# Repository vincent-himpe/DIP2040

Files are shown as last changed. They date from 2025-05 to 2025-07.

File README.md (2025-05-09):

# DIP2040
## An RP2040 in DIP40 PACKAGE with bare minimum on-board circuitry

### Features
- on-board Flash
- on-board 3V reference (LM4040-3.0). Can be disabled by opening a solder bridge.
- ESD protected, sturdy, through-hole, USB-C connector
- Reset and BOObuttones. Boot button also available under the USB-C connector so you can poke it with a paperclip
- Heartbeat LED. can be disabled using a solder bridge
- USB powered 3V3 regulator. Can be strapped to the 3V3 bus using a solder bridge.
- External 3V3 input for self-powered operation
- All GPIO brought out on the pins.  (except the QSPI for the flash). Nothing is hidden.
- Fits standard 40 pin DIP socket
- USB connector extends past the board so you can mount it close to an enclosure wall and have the USB connector stick out.
- 4-layer PCB with ground plane and impedance control.
- 3D STEP model avaiabale
- Design released under Creative Commons Zero Universal.
- Source files available (Altium V25 format)
- Production data available for DKred ( Digikey's PCB service ) and others ( Standard Gerber-X format )

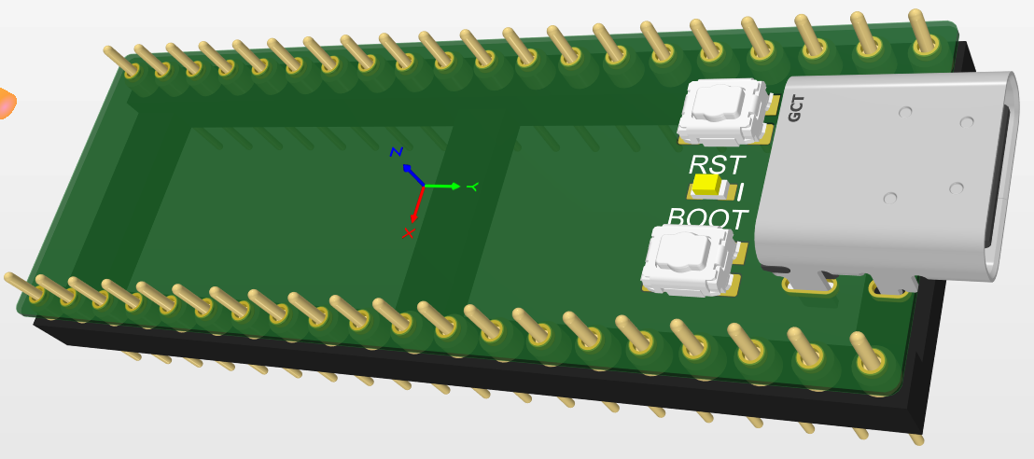
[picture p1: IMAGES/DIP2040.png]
3D view


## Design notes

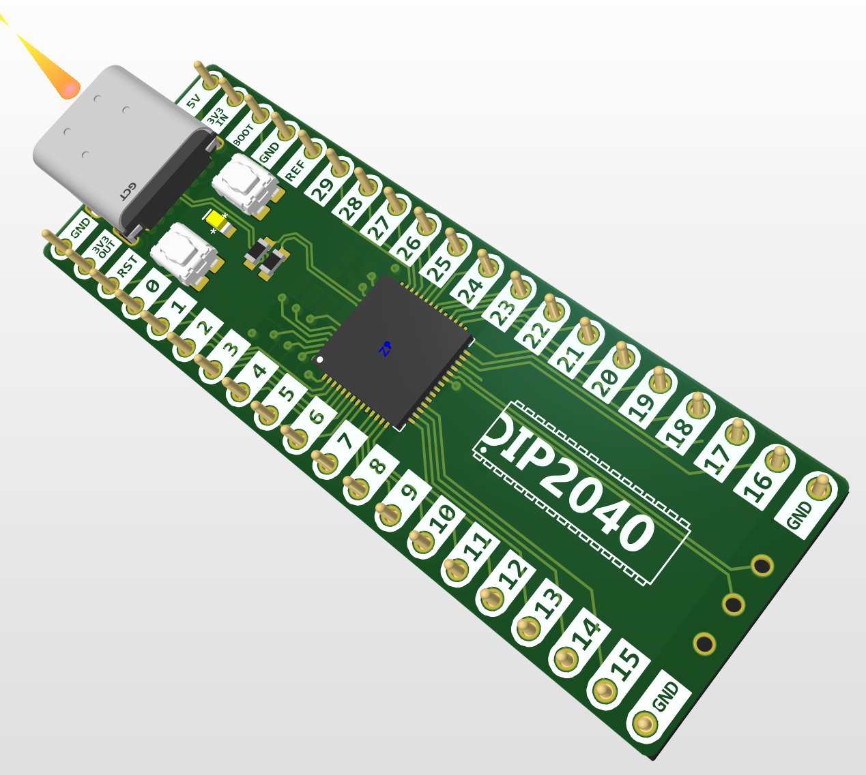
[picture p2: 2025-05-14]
IMAGES/DIP2040B.png

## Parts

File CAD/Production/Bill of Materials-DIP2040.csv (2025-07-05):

Description | Designator | Quantity | LCSC
CAPACITOR,CERAMIC,100nF,16V,X7R,0402 | C1, C7, C10, C11, C13, C14, C15, C16, C17, C20, C22, C23, C26, C27 | 14 | C60474
CAPACITOR,CERAMIC,22uF,16V,X5R,0603 | C2, C3, C4, C5 | 4 | C2762594
CAPACITOR,CERAMIC,4u7,10V,X5R,0402 | C6, C8, C9, C12, C24, C25 | 6 | C1705
CAPACITOR,CERAMIC,15pF,50V,C0G,0402 | C18, C19 | 2 | C3906764
DIODE,TVS,DUAL,UNIDIRECTIONAL,USB | D1 | 1 | C22358704
LED,BLUE,0603 | D2 | 1 | C965807
USB-C, RIGHT ANGLE, [NoValue], RESISTOR,100R,1%,100mW,0603 (1608), IC,PMIC,IDEAL DIODE ORING CONTROLLER | J1, J2, R9, SW1, SW2, SW3, U1, U2 | 8
IND,4.7uH,1.06A,3X3, NRH3012T4R7MN | L1 | 1 | C5159666, C42429096
RESISTOR,5K1,1%,63mW,0402 (1005) | R1, R3 | 2 | C105872
RESISTOR,27R,1%,63mW,0402 (1005) | R4, R5 | 2 | C138021
RESISTOR,10K,1%,63mW,0402 (1005) | R6, R7 | 2 | C60490
RESISTOR,1K,1%,63mW,0402 (1005) | R8, R10 | 2 | C106235
IC,FLASH,QSPI,16Mx8 | U3 | 1 | C97521
IC,PMIC,STEP-DOWN, 2A 3.3V | U4 | 1 | C780769
IC,VOLTAGE REFERENCE,3.0V | U5 | 1 | C460608
IC,RTC,I2C,DS3231M | U6 | 1 | C107410
XTAL,12MHZ,RP2350 | X1 | 1 | C20625731

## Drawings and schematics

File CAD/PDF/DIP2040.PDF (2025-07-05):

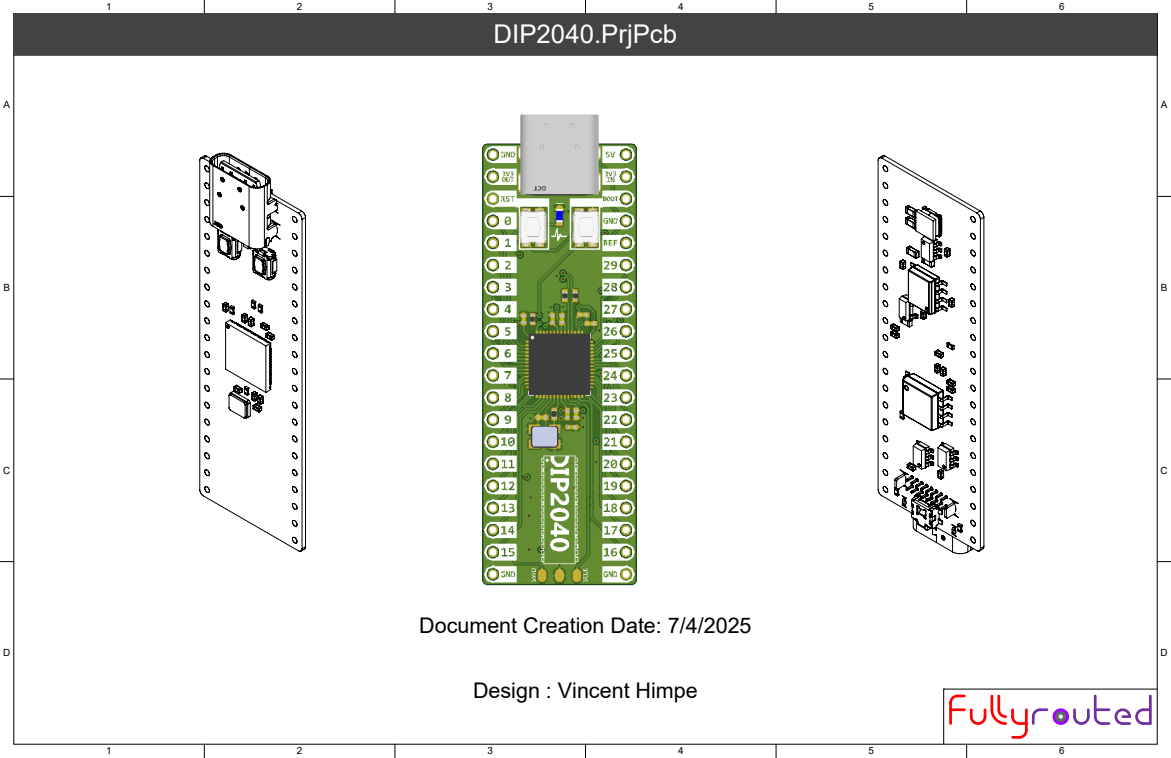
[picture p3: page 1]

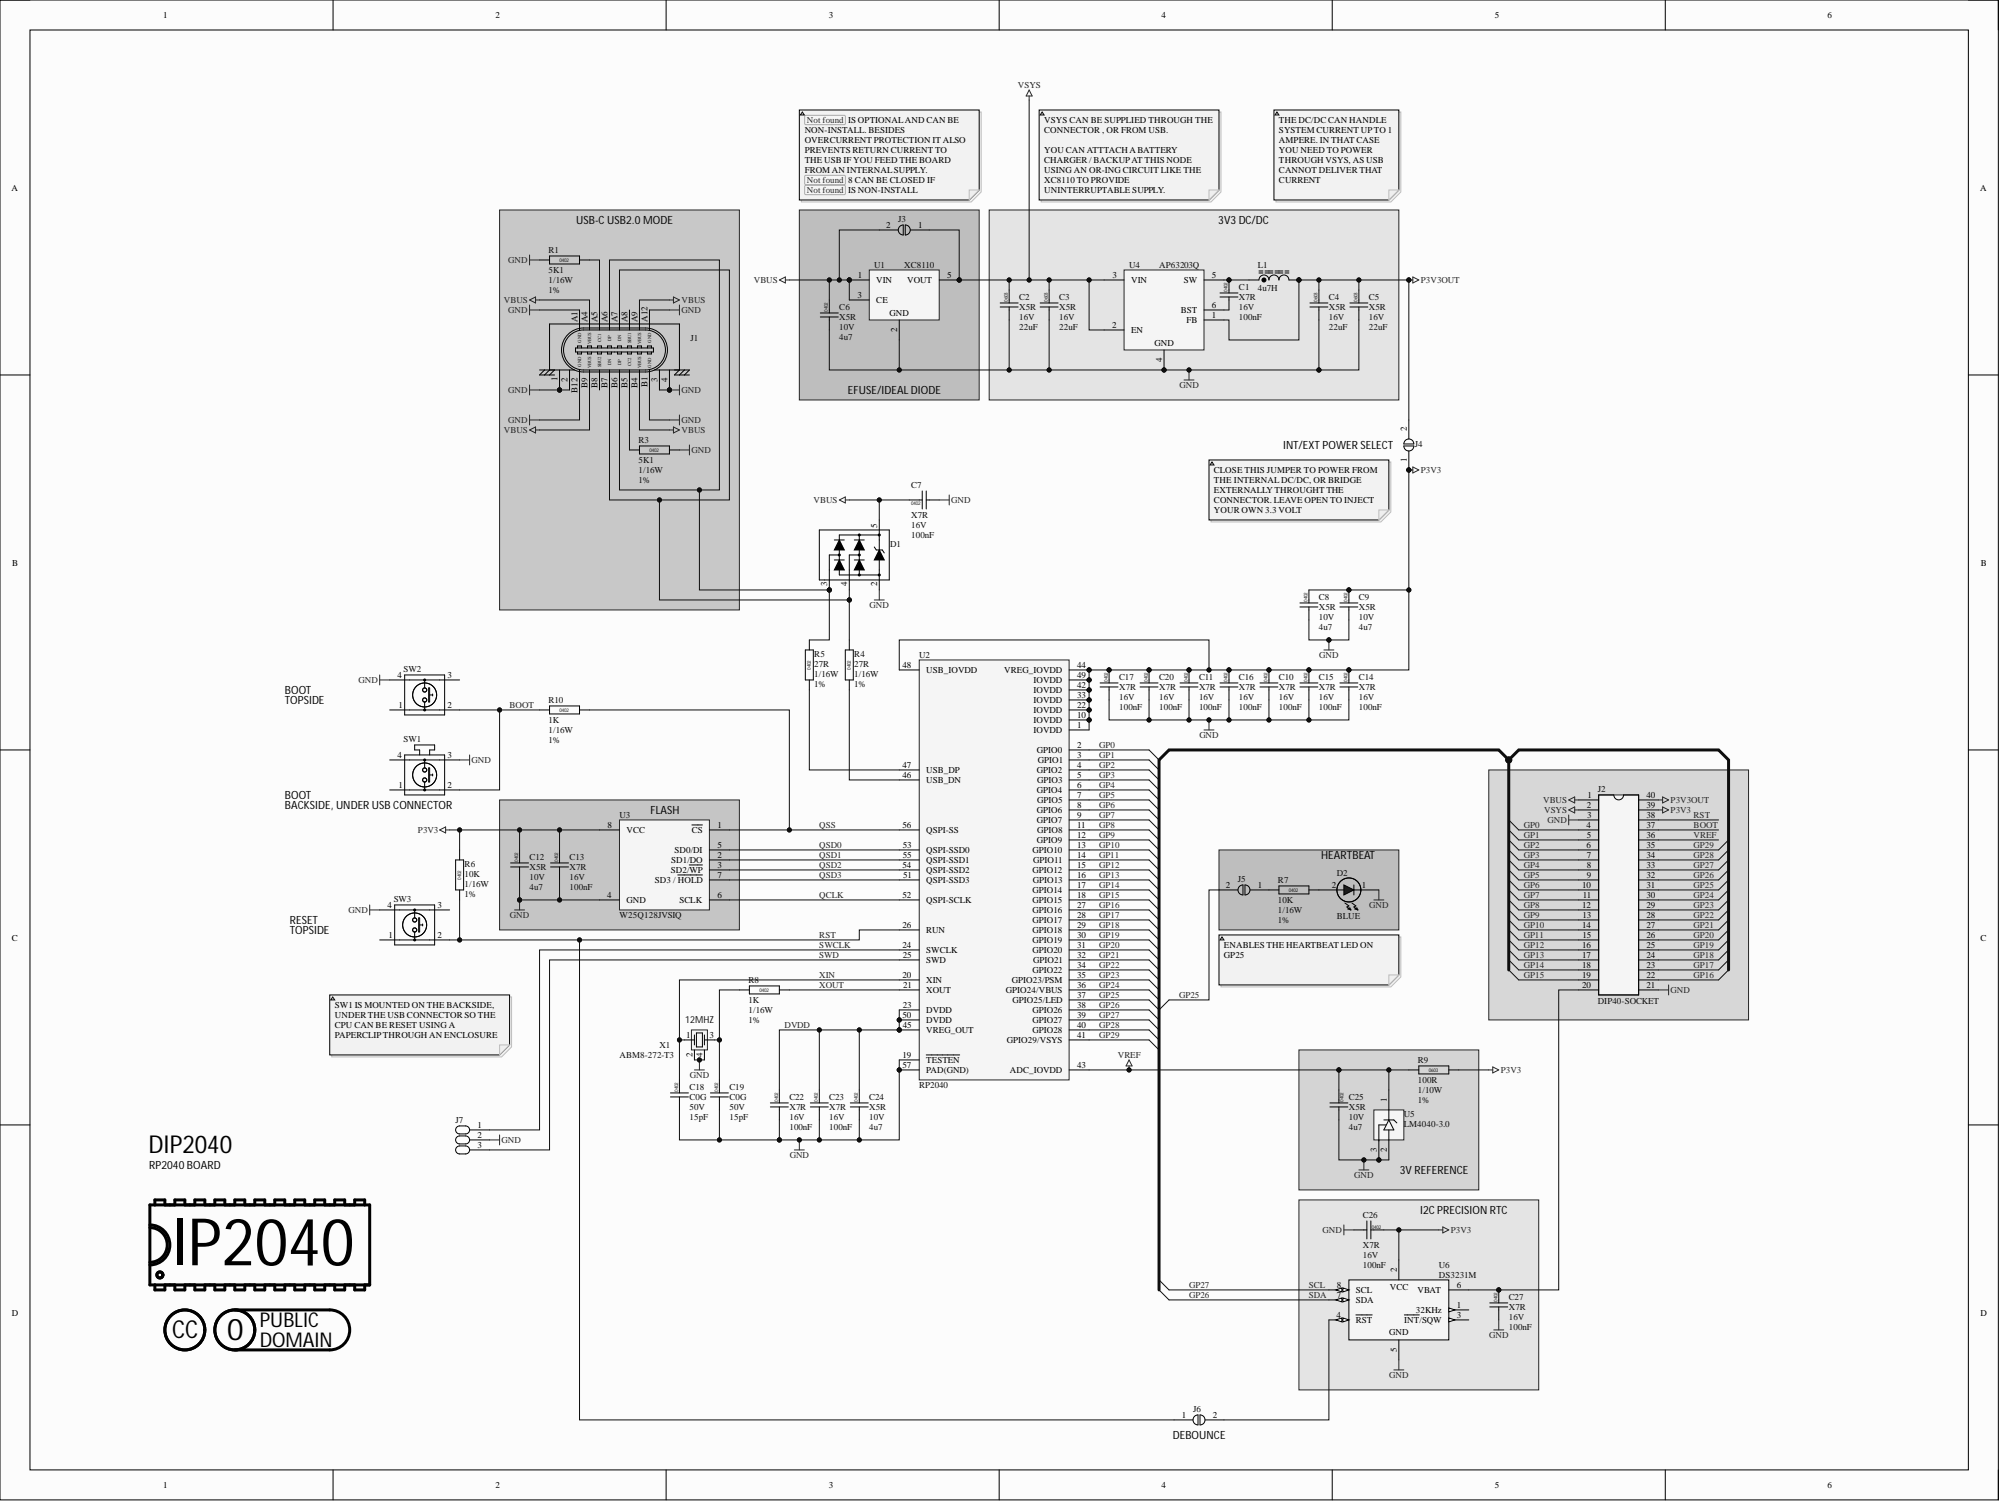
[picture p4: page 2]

Not found IS OPTIONALAND CAN BE
NON-INSTALL. BESIDES
OVERCURRENT PROTECTION IT ALSO
PREVENTS RETURN CURRENT TO
THE USB IF YOU FEED THE BOARD
FROM AN INTERNALSUPPLY.
Not found 8 CAN BE CLOSED IF
Not found IS NON-INSTALL

VSYS CAN BE SUPPLIED THROUGH THE
CONNECTOR , OR FROM USB.

THE DC/DC CAN HANDLE
SYSTEM CURRENT UPTO 1
AMPERE. IN THAT CASE
YOU NEED TO POWER
THROUGH VSYS, AS USB
CANNOT DELIVER THAT
CURRENT

YOU CAN ATTTACH A BATTERY
CHARGER / BACKUP AT THIS NODE
USING AN OR-ING CIRCUIT LIKE THE
XC8110 TO PROVIDE
UNINTERRUPTABLE SUPPLY.

INT/EXT POWER SELECT

CLOSE THIS JUMPER TO POWER FROM
THE INTERNAL DC/DC, OR BRIDGE
EXTERNALLY THROUGHT THE
CONNECTOR. LEAVE OPEN TO INJECT
YOUR OWN 3.3 VOLT

BOOT
BACKSIDE, UNDER USB CONNECTOR

ENABLES THE HEARTBEAT LED ON

SW1 IS MOUNTED ON THE BACKSIDE,
UNDER THE USB CONNECTOR SO THE
CPU CAN BE RESET USING A
PAPERCLIP THROUGH AN ENCLOSURE

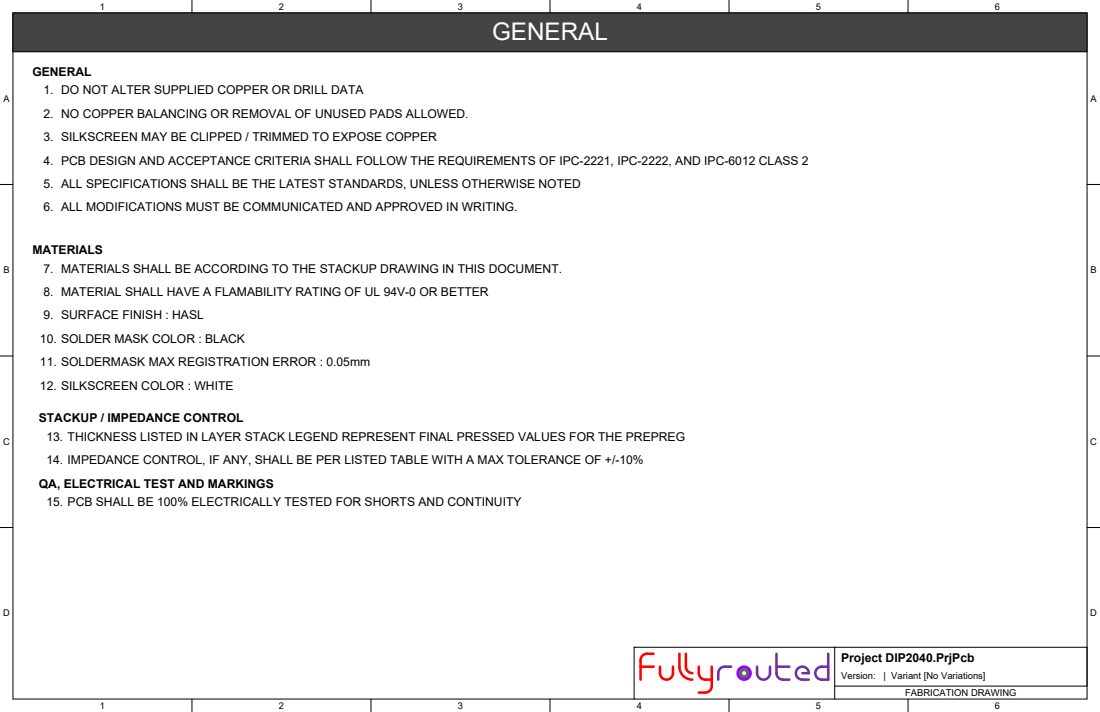
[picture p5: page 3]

GENERAL
1. DO NOT ALTER SUPPLIED COPPER OR DRILL DATA
2. NO COPPER BALANCING OR REMOVAL OF UNUSED PADS ALLOWED.
3. SILKSCREEN MAY BE CLIPPED / TRIMMED TO EXPOSE COPPER
4. PCB DESIGN AND ACCEPTANCE CRITERIA SHALL FOLLOW THE REQUIREMENTS OF IPC-2221, IPC-2222, AND IPC-6012 CLASS 2
5. ALL SPECIFICATIONS SHALL BE THE LATEST STANDARDS, UNLESS OTHERWISE NOTED
6. ALL MODIFICATIONS MUST BE COMMUNICATED AND APPROVED IN WRITING.

MATERIALS
7. MATERIALS SHALL BE ACCORDING TO THE STACKUP DRAWING IN THIS DOCUMENT.
8. MATERIAL SHALL HAVE A FLAMABILITY RATING OF UL 94V-0 OR BETTER
9. SURFACE FINISH : HASL
10. SOLDER MASK COLOR : BLACK
11. SOLDERMASK MAX REGISTRATION ERROR : 0.05mm
12. SILKSCREEN COLOR : WHITE

STACKUP / IMPEDANCE CONTROL
13. THICKNESS LISTED IN LAYER STACK LEGEND REPRESENT FINAL PRESSED VALUES FOR THE PREPREG
14. IMPEDANCE CONTROL, IF ANY, SHALL BE PER LISTED TABLE WITH A MAX TOLERANCE OF +/-10%
QA, ELECTRICAL TEST AND MARKINGS
15. PCB SHALL BE 100% ELECTRICALLY TESTED FOR SHORTS AND CONTINUITY

Project DIP2040.PrjPcb
Version: | Variant [No Variations]

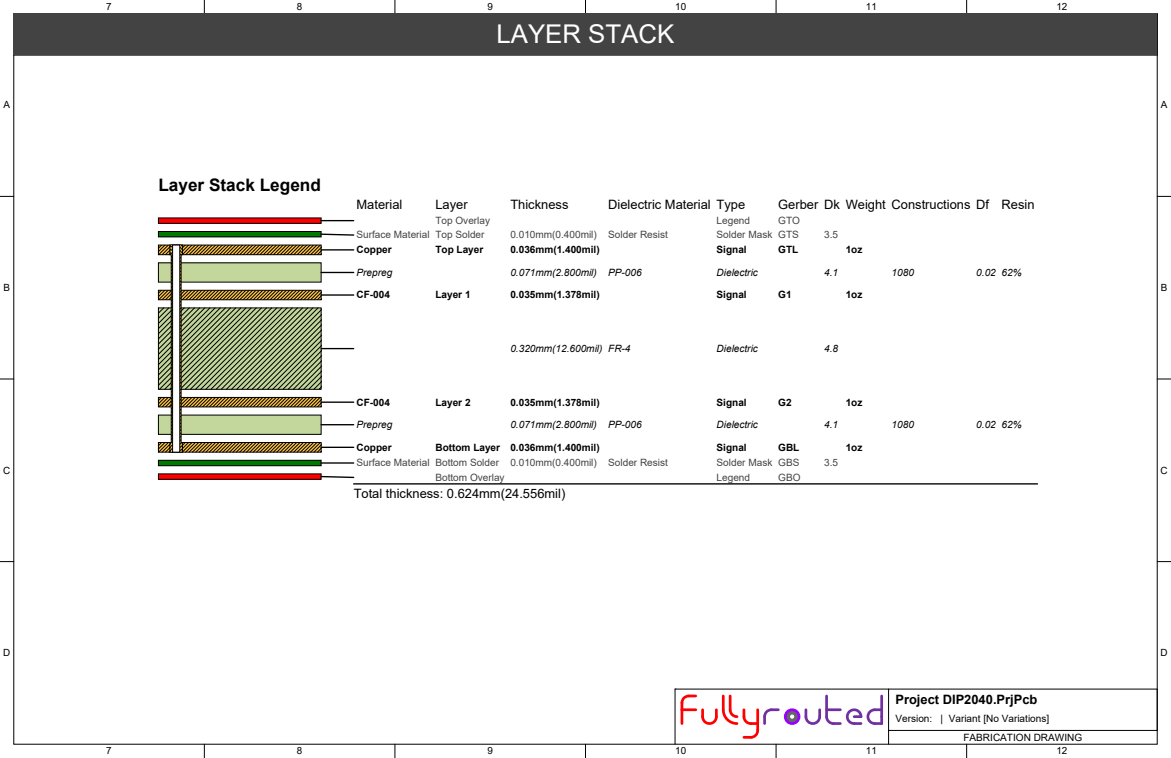
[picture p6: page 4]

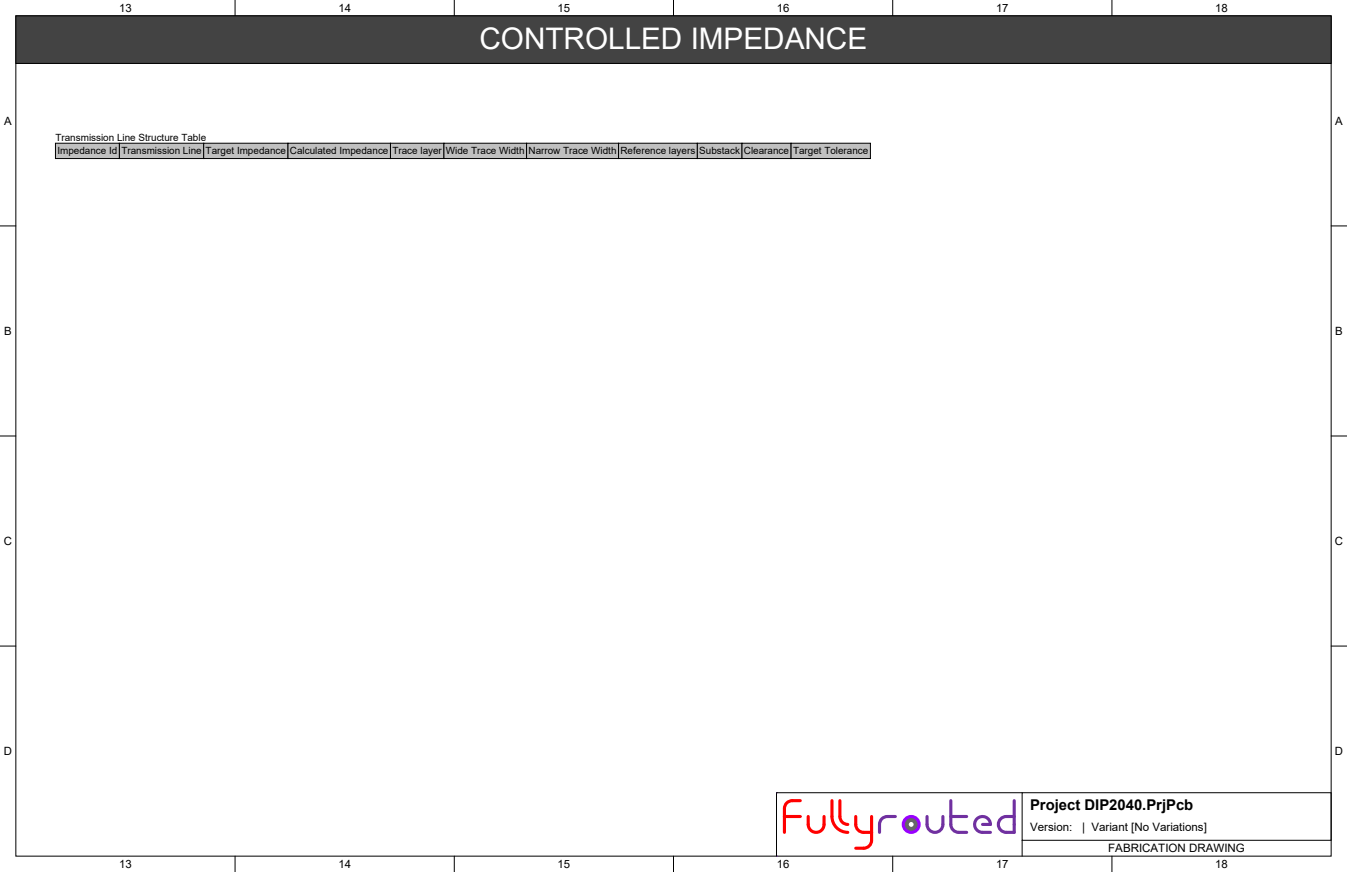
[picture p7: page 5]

Transmission Line Structure Table

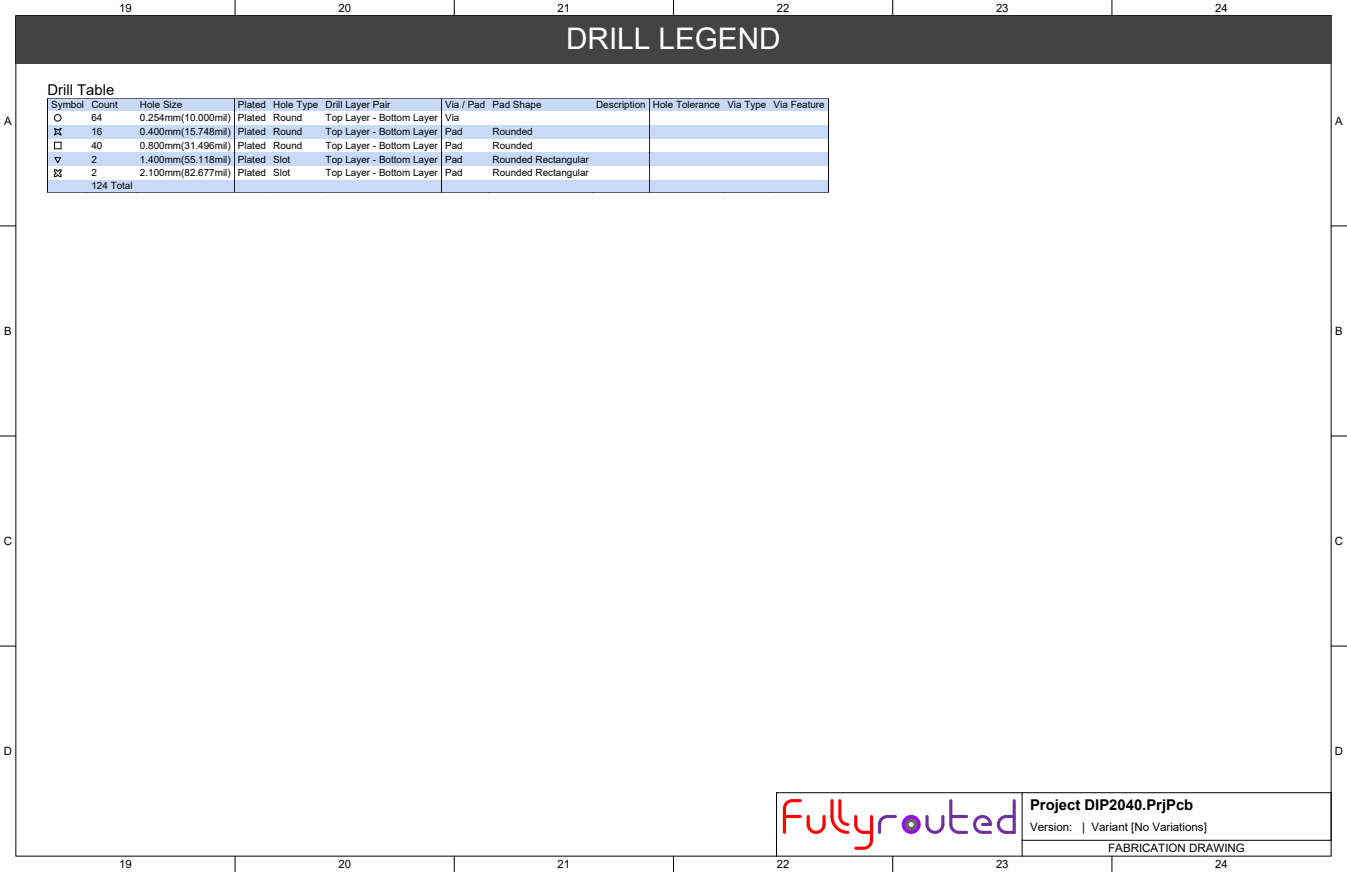
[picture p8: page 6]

Symbol | Count | Hole Size | Plated | Hole Type | Drill Layer Pair | Via / Pad | Pad Shape | Description | Hole Tolerance | Via Type | Via Feature

64 | 0.254mm(10.000mil) | Plated | Round | Top Layer - Bottom Layer | Via
16 | 0.400mm(15.748mil) | Plated | Round | Top Layer - Bottom Layer | Pad | Rounded
40 | 0.800mm(31.496mil) | Plated | Round | Top Layer - Bottom Layer | Pad | Rounded
2 | 1.400mm(55.118mil) | Plated | Slot | Top Layer - Bottom Layer | Pad | Rounded Rectangular
2 | 2.100mm(82.677mil) | Plated | Slot | Top Layer - Bottom Layer | Pad | Rounded Rectangular
124 Total

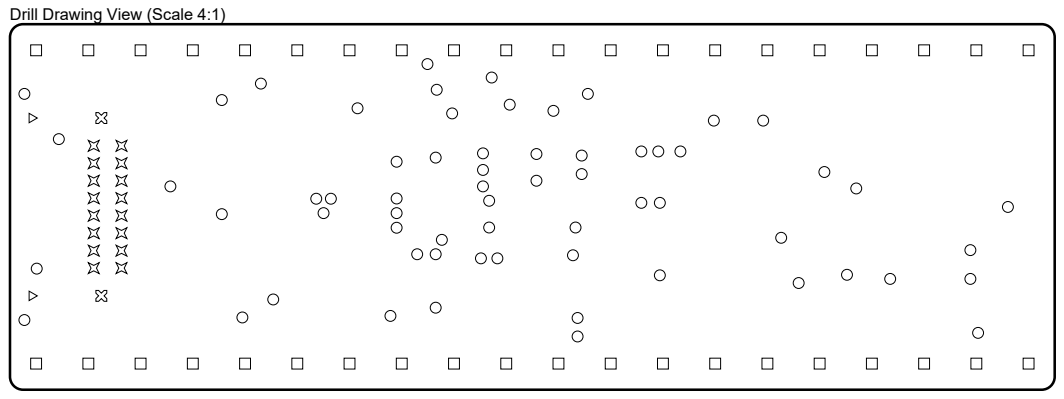
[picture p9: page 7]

Drill Drawing View (Scale 4:1)

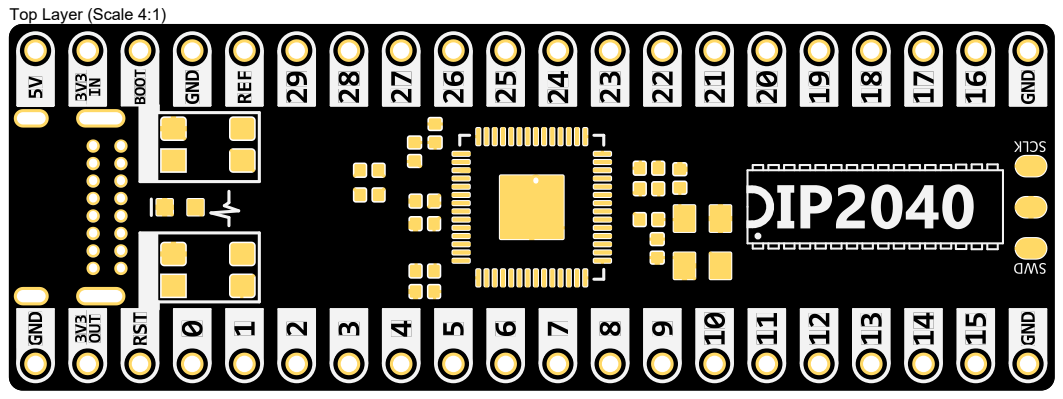
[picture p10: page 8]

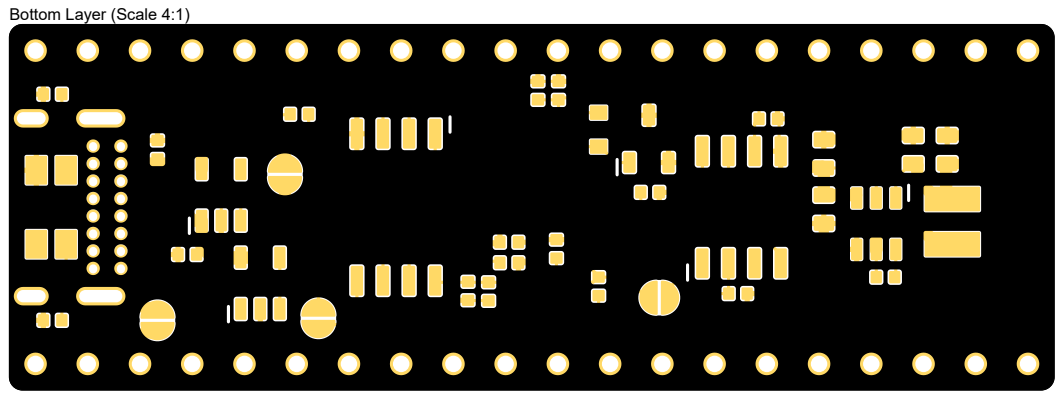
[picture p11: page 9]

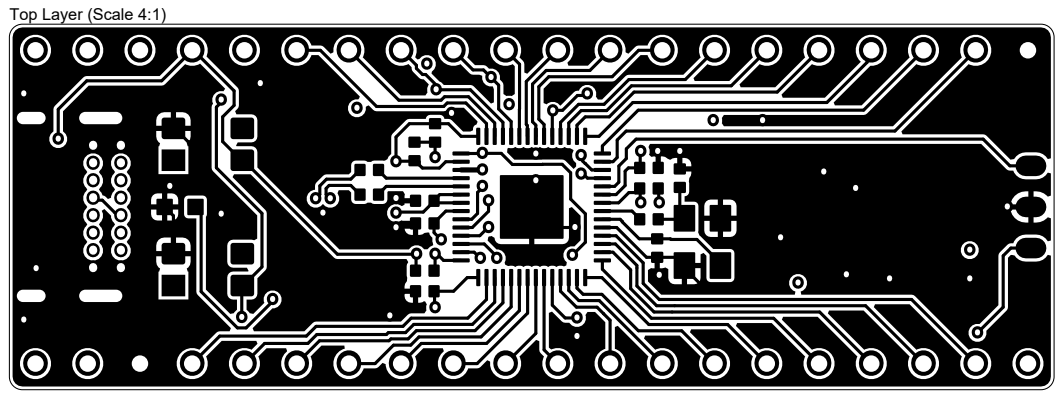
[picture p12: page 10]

LAYER VIEW : TOP LAYER

LAYER VIEW : MID LAYER 1

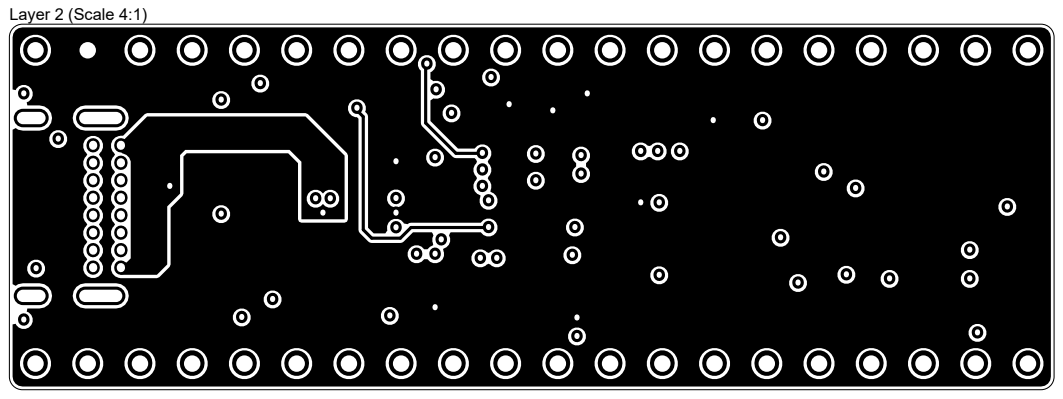
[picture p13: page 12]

LAYER VIEW : MID LAYER 2

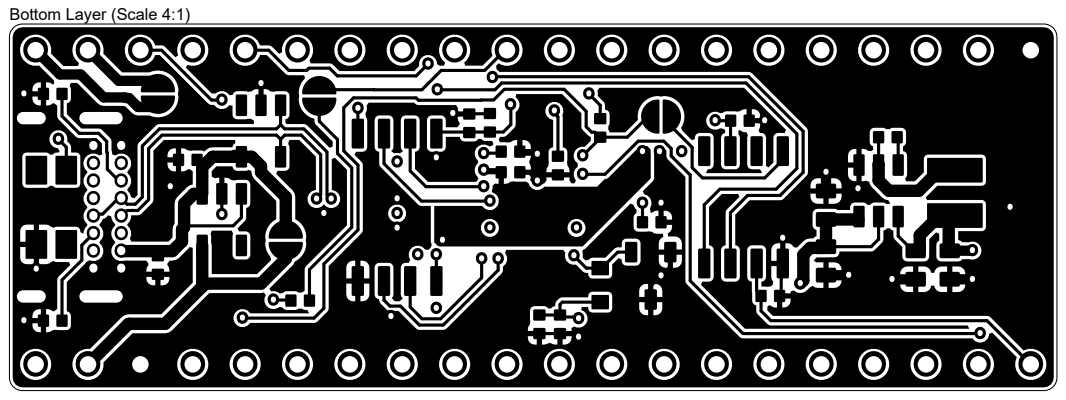
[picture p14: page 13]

LAYER VIEW : BOTTOM LAYER


LAYER VIEW : TOP SOLDER MASK


LAYER VIEW : BOTTOM SOLDER MASK


LAYER VIEW : TOP SILKSCREEN (LEGEND)


LAYER VIEW : BOTTOM SILKSCREEN (LEGEND)


Unless otherwise specified the following rules apply:
1. DO NOT DEVIATE FROM ARTWORK OR BOM WITHOUT PRIOR AUTHORIZATION.
2. ASSEMBLE AND INSPECT PER IPC-610 CLASS 2

Bill of Materials and Material Handling
3. THE BOM CONTAINED IN THIS DOCUMENT IS AS-BUILT. NON-INSTALLED PARTS HAVE BEEN REMOVED. ADDITIONAL BOM FORMATS ARE AVAILABLE IN THE PROJECT FILES
4. ANY PART SUBSTITUTIONS MUST BE APPROVED IN WRITING BEFORE ASSEMBLY
5. ALL MATERIALS MUST BE PROCURED FROM MANUFACTURER AUTHORIZED DISTRIBUTORS OR THE ORIGINAL MANUFACTURER
6. ALL COMPONENTS AND BOARDS TO BE HANDLED AND STORED ACCORDING TO IPC GUIDELINES
7. ESD CONTROL PER IPC RULES

Soldering
8. SOLDERING TO BE DONE USING SN37PB63 ALLOY USING ALLOY MANUFACTURER RECOMMENDED NO-CLEAN FLUX
9. BGA COMPONENTS WITH LEAD-FREE CONNECTIONS NEED TO BE REBALLED WITH SN63PB37. MIXING OF ALLOYS IS NOT PERMITTED.
10. SOLDERING PREFERRABLY TO BE DONE USING NITROGEN ATMOSPHERE
11. SURPLUS COMPONENTS TO VACUUM SEALED WITH DESSICANT IN ANTISTATIC BAGS
12. INCOMING MATERIAL (BOARDS AND COMPONENTS) NEEDS TO BE INSPECTED FOR HUMIDITY AND BAKED IF NEEDED PRIOR TO USE.
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

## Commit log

2025-05-09 INITIAL COMMOIT
    [DIP2040.PcbDoc, DIP2040.PrjPcb, DIP2040.SchDoc]
2025-05-09 WORK IN PROGRESS
    [DIP2040.PcbDoc, DIP2040.SchDoc]
2025-05-10 UPDATES
    UPDATES
    [DIP2040.PrjPcb, DIP2040.SchDoc]
2025-05-14 EDITS
    EDI
    [DIP2040.PcbDoc]
